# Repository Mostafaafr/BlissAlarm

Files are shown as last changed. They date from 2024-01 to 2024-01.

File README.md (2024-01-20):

Review Assignment Due Date (https://classroom.github.com/a/2yGso8Cl)
# A14-Final Submission
    * Team Number: 13
    * Team Name: BlissAlarm
    * Team Members: Mostafa Afr and Abir Hossain

# Section 1: Video Presentation
Find the video here: https://www.youtube.com/watch?v=Qn7JugjathM&ab_channel=MostafaAfr
Video (https://www.youtube.com/watch?v=Qn7JugjathM&ab_channel=MostafaAfr)

# Section 2: Project Photos & Screenshots

## Final Project Look
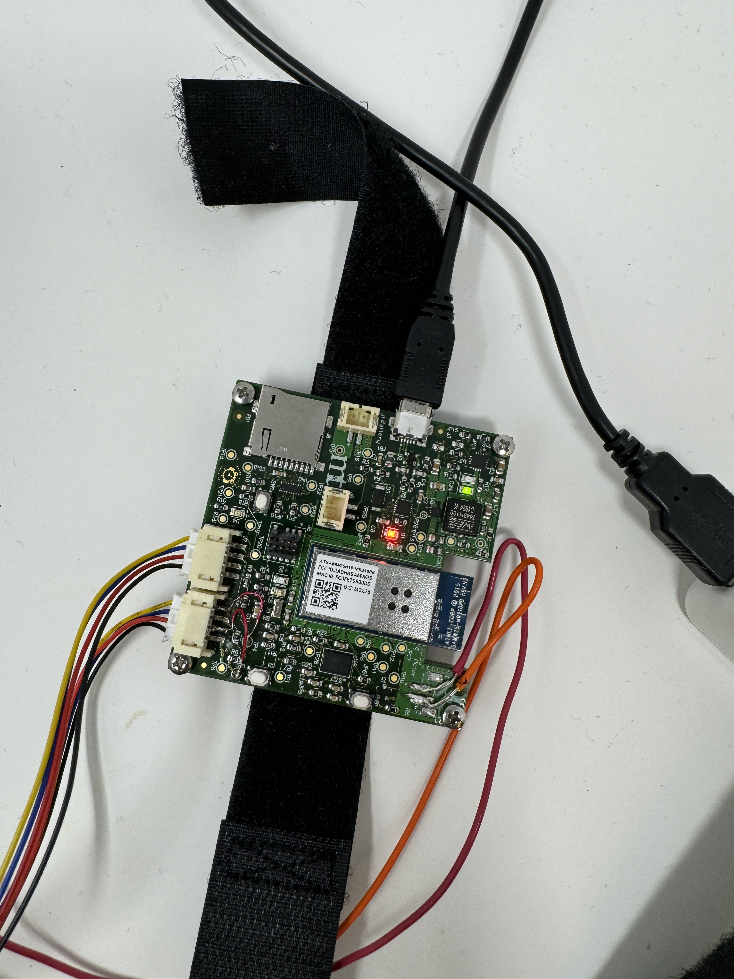
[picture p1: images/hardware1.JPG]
hard1

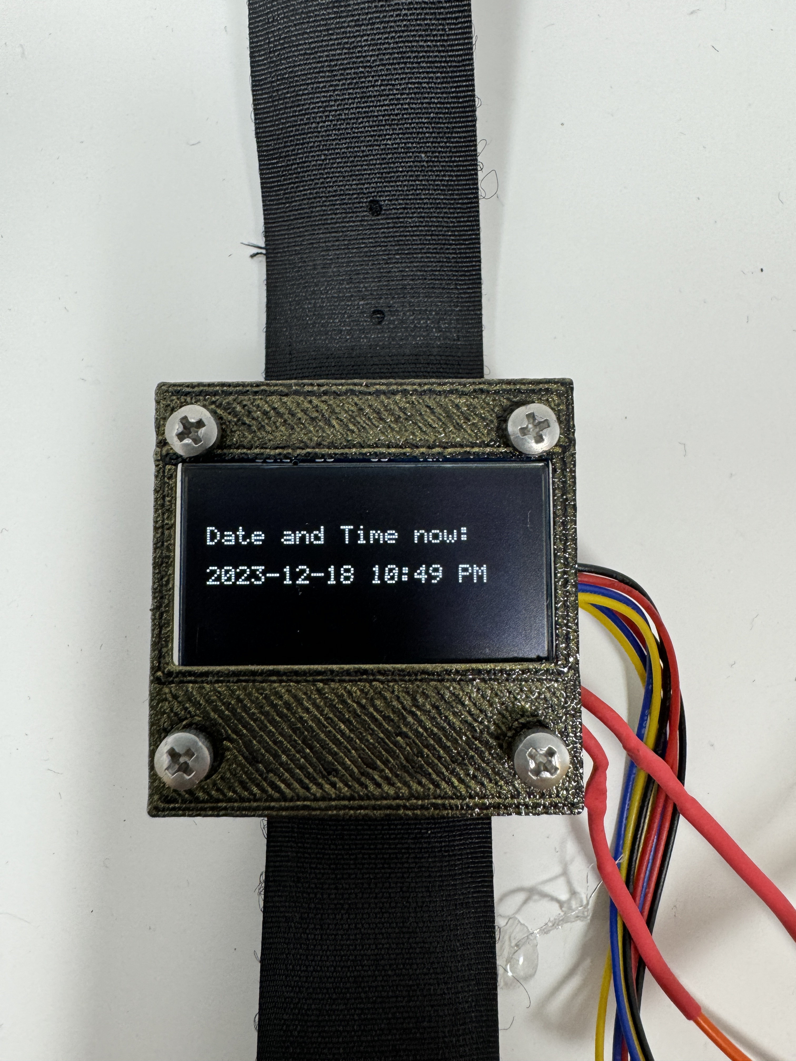
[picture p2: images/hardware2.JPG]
hard2

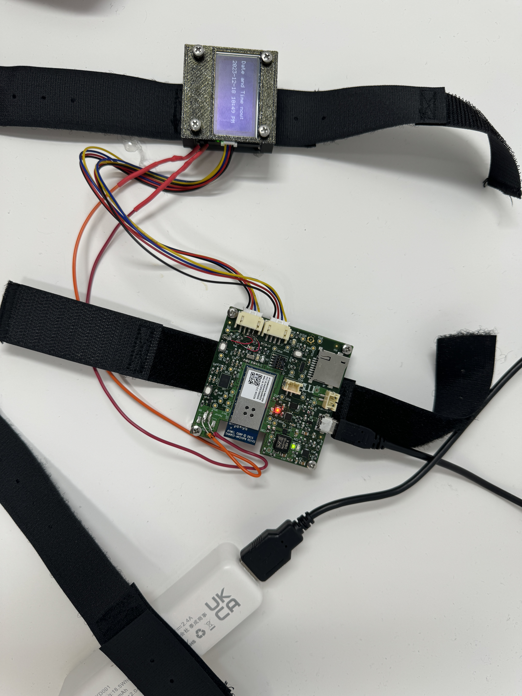
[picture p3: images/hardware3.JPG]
hard3

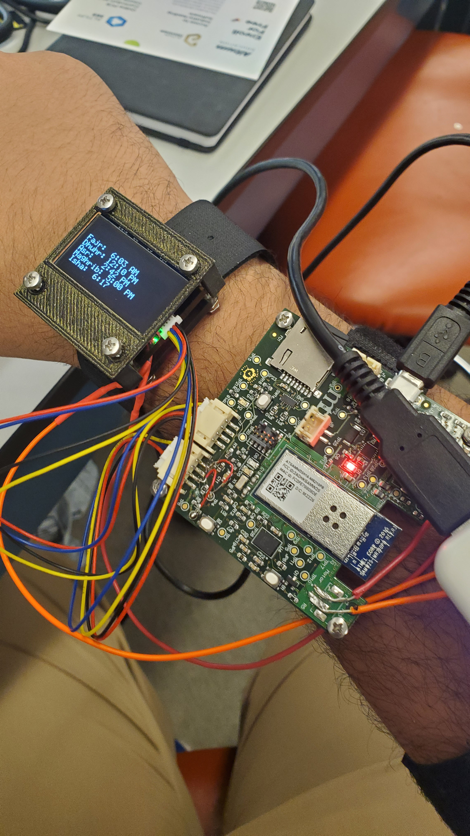
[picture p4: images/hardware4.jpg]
hard4


## PCBA Pictures

### Top 
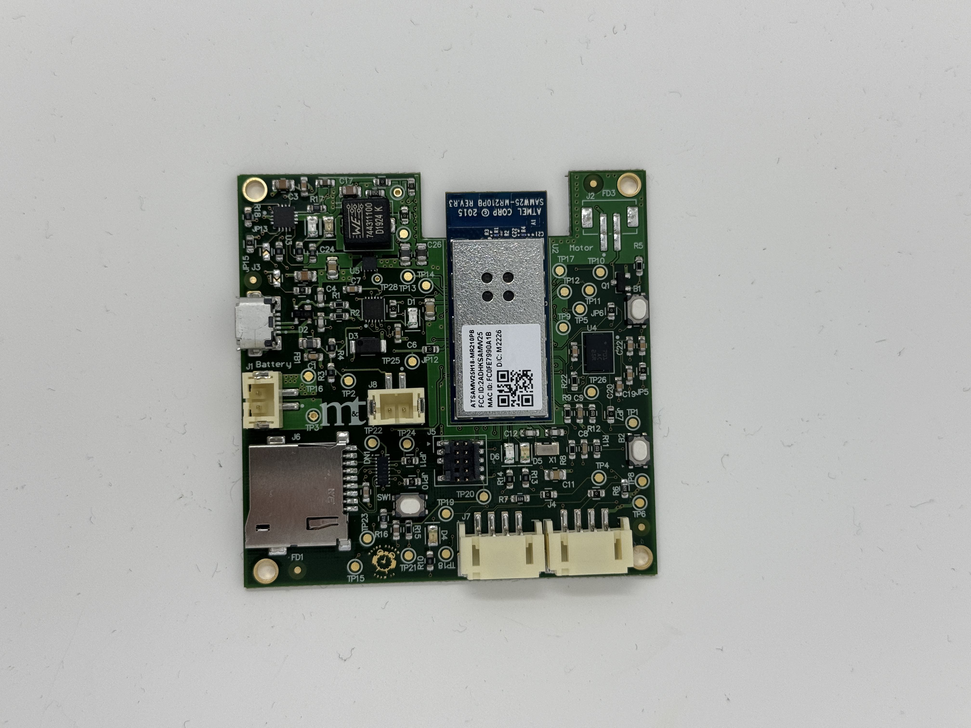
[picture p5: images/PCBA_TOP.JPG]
topPCB

### Bottom 
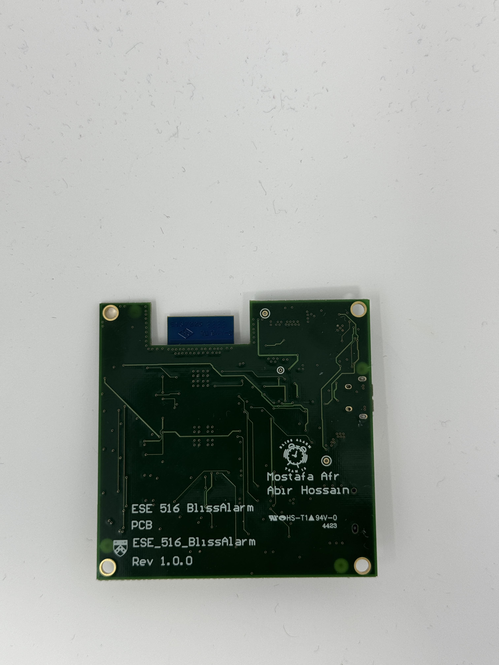
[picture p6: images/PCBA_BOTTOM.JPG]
bottomPCB


## Thermal Images
thermal pic

## Altium Designs

### 2D View
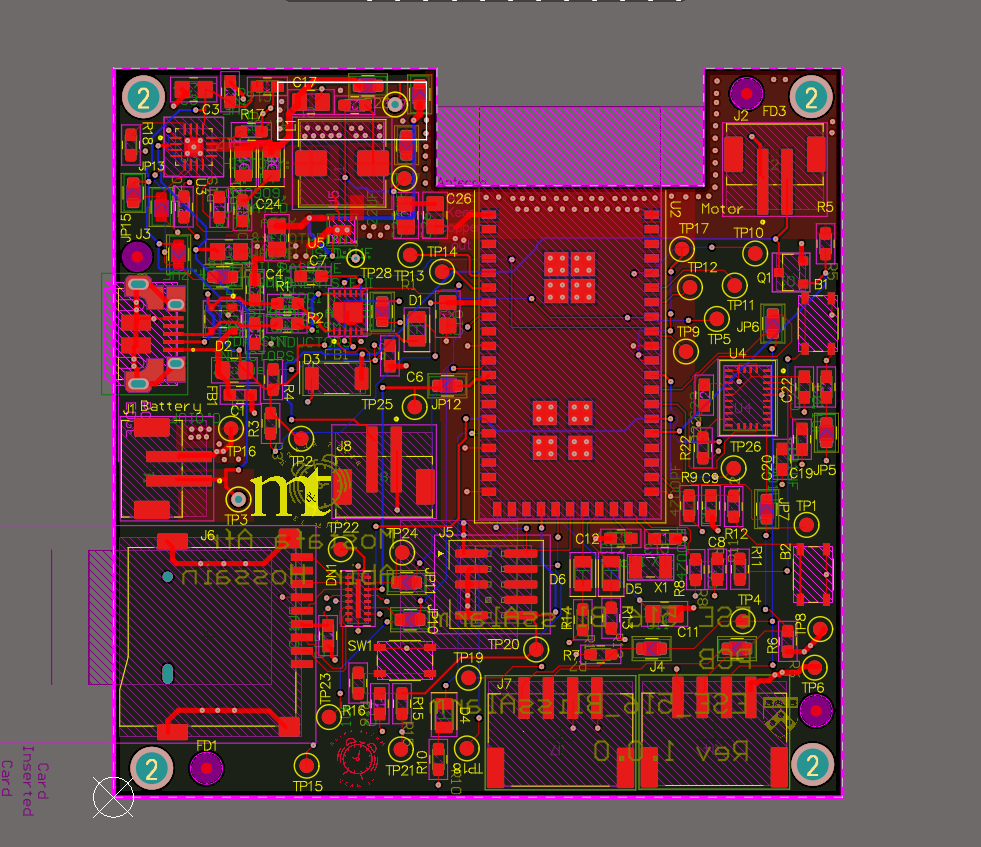
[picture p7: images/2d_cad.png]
2dview

### 3D View
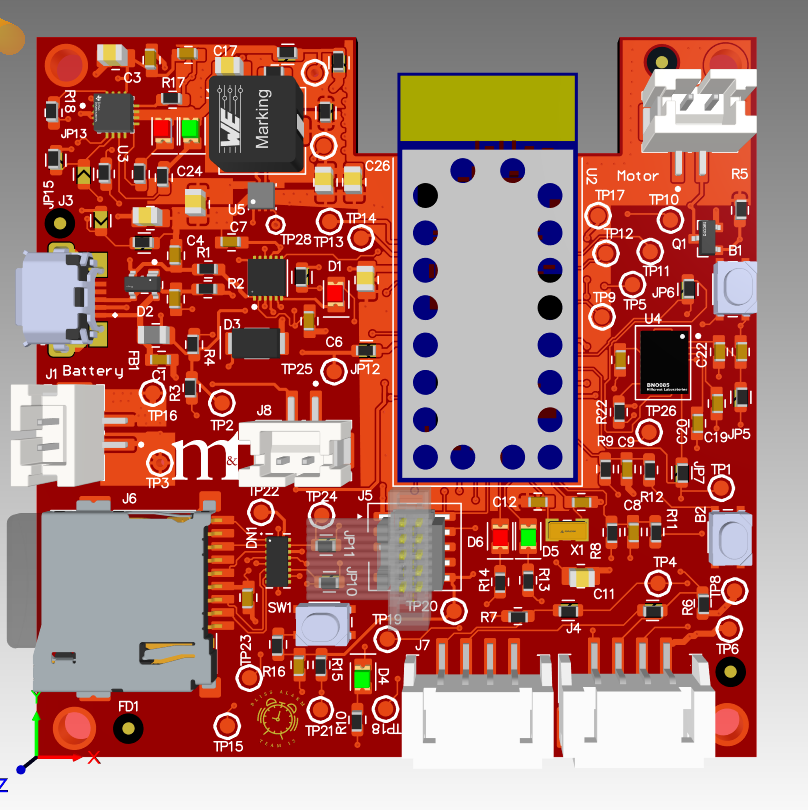
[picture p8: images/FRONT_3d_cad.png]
3dfront
* Top: 
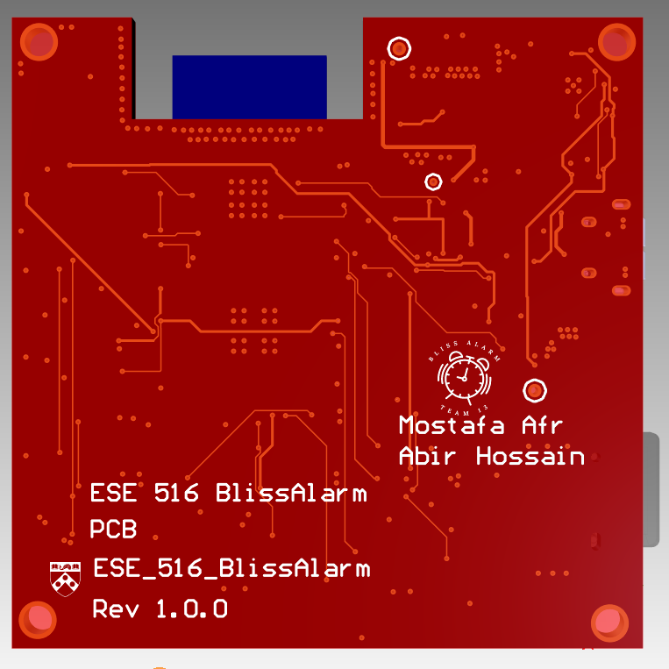
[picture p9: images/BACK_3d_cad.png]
3dback
* Bottom: 

## Node RED Dashboard

### Node RED Frontend
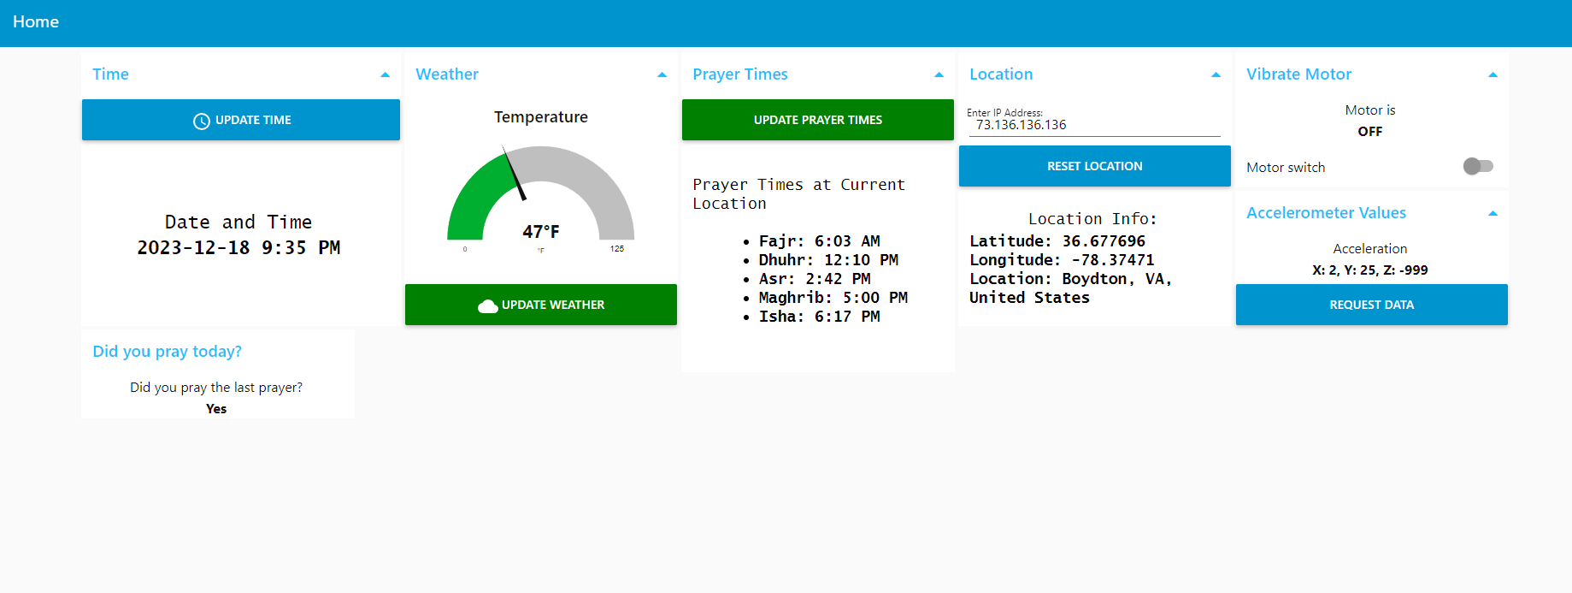
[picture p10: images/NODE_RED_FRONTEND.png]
nodeRed

### Node RED Backend
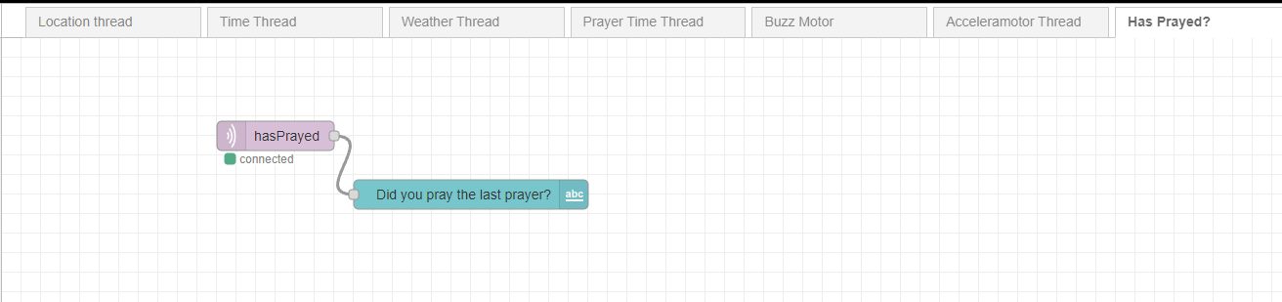
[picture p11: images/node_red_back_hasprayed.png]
prayed
* Checking if prayed: 
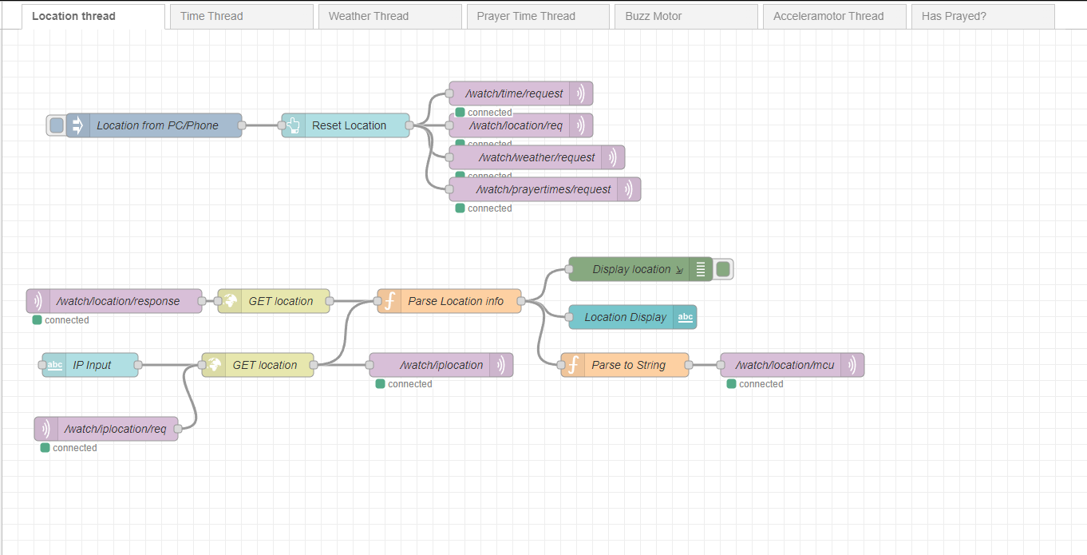
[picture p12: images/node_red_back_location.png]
location
* Location: 
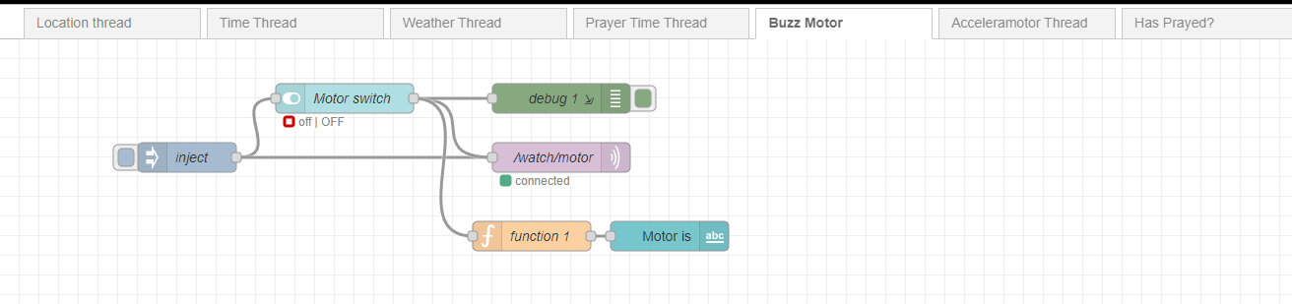
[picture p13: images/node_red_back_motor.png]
motor
* Motor: 
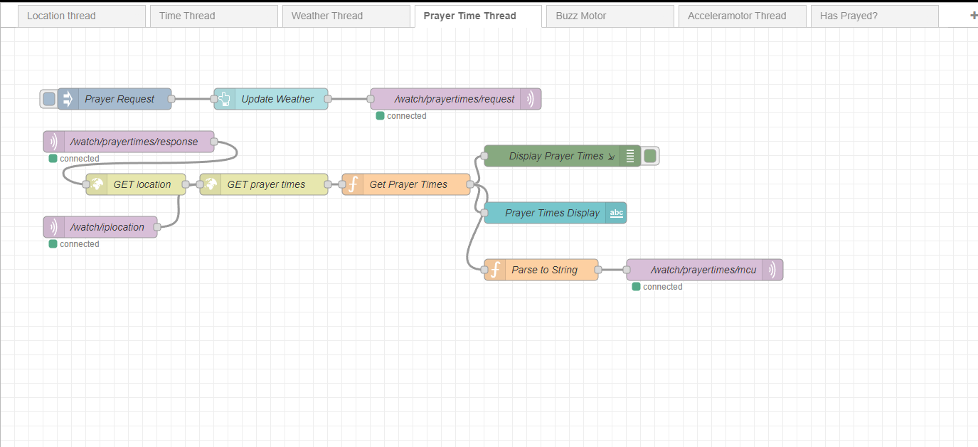
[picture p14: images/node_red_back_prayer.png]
prayer
* Prayer: 
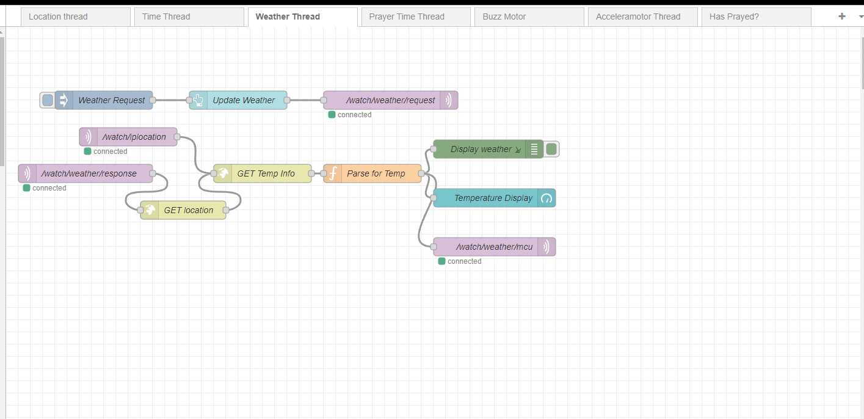
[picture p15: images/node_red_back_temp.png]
temp
* Temperature: 
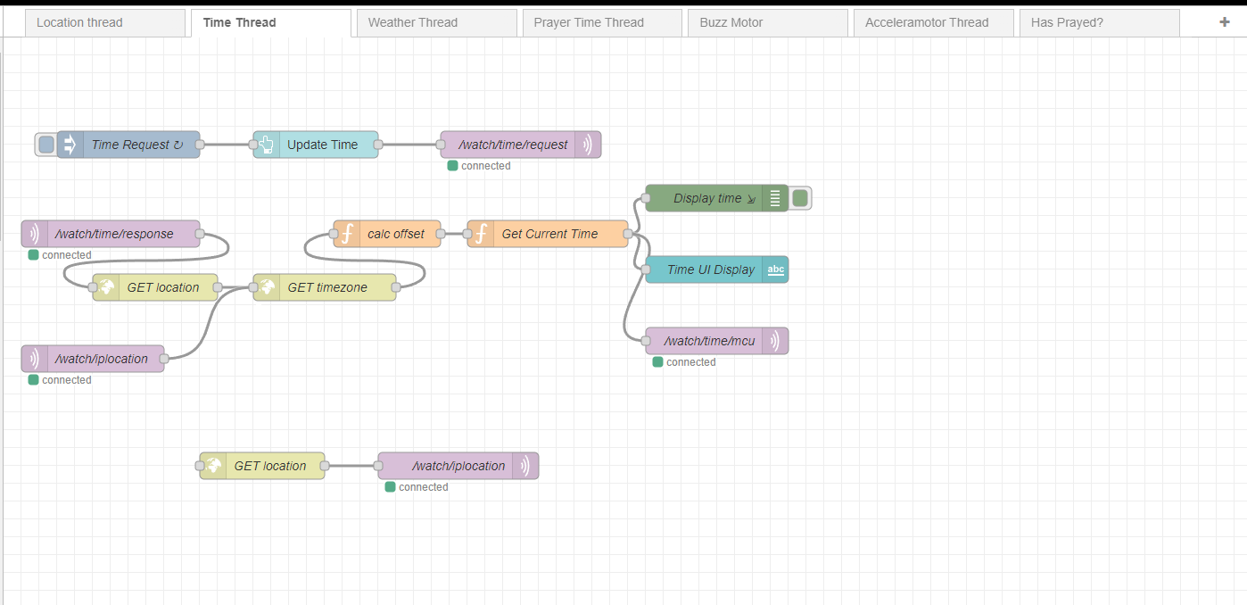
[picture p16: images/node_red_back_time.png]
time
* Time: 

## Block Diagaram
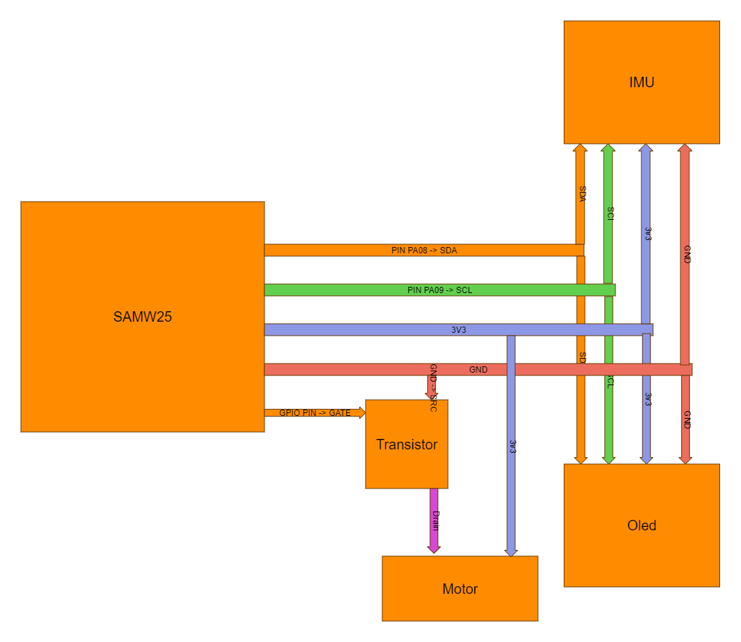
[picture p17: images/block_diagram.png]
blockDiag


# Section 3: Project Summary
## Device Description
Our project solves the issue of Muslims missing prayer times either due to sleep or even during the day. Prayer times change every single day since they are based on the sun’s movement (sunrise, midday, sunset, etc.), and it can be difficult to set an alarm every day for prayer or to always remember to pray on time. Our device connects to the internet and automatically pulls the date, time, and prayer times for that date. It then senses whether you’ve prayed or not using an accelerometer to track if you’ve done the movements for prayer. If you haven’t prayed and the prayer time is coming to an end soon, it will send vibrations with a haptic motor to remind you to pray.

## Inspiration
We were inspired to do this project by Mostafa's 200+ (not joking) alarms on his phone. He can’t wake up to normal alarms well but needs to pray before sunrise every morning, and a strong vibration if you haven’t prayed would be really helpful! This is the case for man Muslims and especially students who have terrible sleep schedules.

## Device Functionality
So the device design is fairly simple. It’s a microcontroller that connects to an OLED via I2C to display things like time, prayer time, etc. It connects to an accelerometer via I2C as well and checks the values at a set interval to try and detect the motions of prayer. It then connects to a haptic motor via a GPIO pin that vibrates if you haven’t prayed. The MCU is WiFi capable, so it connects to MQTT broker on our Azure server which then connects to Node RED to send and receive the data it needs to display. The casing for the watch is 3D printed to fit all the components inside (besides the PCBA which is too large due to the extra testing/debugging components we added). There are also laser cut pieces of acrylic for the bottom of the watch as it made it easier to take apart the watch for debugging. The parts are screwed together or held with adhesive and an ESD strap is used for the watchstrap.

## Project Links
### Node RED Instance
* Backend: http://20.102.106.224:1880/
* Frontend: http://20.102.106.224:1880/ui

### PCBA Link
Altium: https://upenn-eselabs.365.altium.com/designs/55E08EC9-9D23-40D7-89CE-D9C51BA8A47B

## Challenges
We had many, many challenges throughout this project. Our IMU was a major challenge. The IMU we had on our board turned out to have incredibly complex drivers that were difficult to port as it was made for arduino/raspberrypi, and it had its own protocol that wasn’t quite I2C but used I2C in it. We had to switch to a different accelerometer, but thankfully we had an extra JST connector. That extra JST connector unfortunately had the SCL and 3V3 pins swapped, and the trace for the 3V3 pin was really short. That took a couple hours to debug between figuring out the problem, carefully using the knife, and then soldering and resoldering the leads on tight points. We also had many struggles with FreeRtos causing issues. When we pulled pins high they went to .5V instead of 3.3V which is just really weird. We messed with our RTOS scheduling and it fixed it. We had a lot of trouble finding our IMU using I2C even after we switched, which is really odd too. RTOS again caused some issues. We got weird stack overflow errors that sometimes fixed when we unplugged our accelerometer or board. We also had issue with scheduling and getting all of our peripherals to simultaneously work, as sometimes one worked but blocked another. We had problems with MQTT in general as that also had some just weird errors like the Detkin wifi also causing a stack overflow error. We had issues with the screws being too long on our casing and also the casing damaging the OLED we were using (I think that’s what happened at least). Our debug buttons also didn’t work which may have been our own fault in our altium design. A number of things just went wrong and it would take forever to list them all here. We overcame them by asking others in lab for help, reading online, or just trying different things. Each problem came with a set of debugging steps to find a unique solution. Sometimes it was altium, sometimes it was hardware, a lot of times it was RTOS, and sometimes it was unknown Heisenbugs. 

## Prototype Learnings
We learned how to do Altium which we both came in knowing nothing about. That came with a general knowledge of PCBs that we plan to continue into my other products We learned a lot about embedded systems and I2C as well, RTOS, bootloaders, Github, we’ve come out of this class knowing a lot of very necessary skills for prototyping our own projects. We also learned about Node RED and setting up a server, both very useful skills. Node RED in particular is really cool and a nice approach to IoT compared to what we’d done in say ESE 111 with Blynk. We learned about prototyping with different MCUs, particularly a less common one than we did in ESE 350. We even used laser cutting and 3D printing in our final design. We learned a lot of prototyping techniques with regard to coding drivers and picking peripherals and making BOMs (although really boring) that will definitely be useful in our future! If we had to build the device again (which we are actually considering!) we would remove a lot of debugging components since we’ve tested them already. We would fix our mistake of swapping the SCL and 3V3 pins and fix our buttons. We’d definitely use a smaller MCU to make the PCB fit in the watch and choose a bigger screen since those are popular for watches. We’d also change the IMU we are using. Size is really important for our design so we would do a lot of trimming of things to save space.

## Next Steps
We think the steps needed to improve the project are a lot of what we mentioned in question 5. But aside from that, we think we could add a gyroscope. It proved too difficult this time around, but we could do it with more time perhaps. We would also improve the casing to look more professional. We would also work on reliability of the product, as a prototype has its bugs. We would likely add more to the UI on the screen, we think it is fine now, but making it a bit more aesthetic could help it stand out better as a watch. Adding an app could be really helpful too. We also think we should be mainly focusing on size and squeezing the PCB to a much smaller size by shrinking the MCU. 

## Takeaways from ESE 5160 
We learned altium exceptionally well, and learned a lot about I2C. We gained a general understanding of what embedded systems looks like in industry, with power planning, peripheral selection, PCB design, driver coding, etc. We improved in our general knowledge of RTOS based systems, MCUs, etc., and came out just better embedded engineers. We still have a lot to learn, but this was a great introduction to intermediate embedded systems, and we come away with the confidence and ability to build more complex projects!

# Section 4: Codebase
## Attributions for Driver Code

### OLED Driver:
For the OLED Driver, we ported a driver we found on GitHub by elektro155, which can be found at https://github.com/elektro155/OLED-display-SSD1306-library-converted-for-ARM-C-language/tree/master. We attempted to make our own driver, but for this specific OLED it proved to be difficult. The author fo the driver did not post any rules about any specific requirements for attributions. 

### IMU Driver:
For the IMU, we used the IMU that was already used in a previous assignment, so we copied over the driver for that into our final demo. 

### Motor Driver:
We wrote this driver ourselves, and it was on the easier end to do as it was just manipulating the state of a GPIO pin for certain lengths of time.

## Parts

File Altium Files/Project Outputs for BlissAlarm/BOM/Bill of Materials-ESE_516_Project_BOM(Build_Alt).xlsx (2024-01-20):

Line # | Name | Description | Designator | Revision ID | Revision Status | Quantity | Footprint | PCB Package | Fitted | Manufacturer 1 | Manufacturer Part Number 1 | Manufacturer Lifecycle 1 | Supplier 1 | Supplier Part Number 1 | Supplier Unit Price 1 | Supplier Subtotal 1 | CompanyName
 | JST PH to SH Cable |  | A3 |  |  | 1 |  |  |  | Adafruit Industries | 4424 | Unknown | Mouser | 485-4424 | 0.95 | 0.95
 | Vibrating Motor Disc |  | A2 |  |  | 1 |  |  |  | Adafruit Industries | 1201 | Unknown | Mouser | 485-1201 | 1.95 | 1.95
 | 0603 link | 0O link, SMD, 0603, Solder Bridge Option | JP1, JP2, JP3, JP4, JP5, JP6, JP7, JP8, JP9, JP10, JP11, JP12, JP13, JP16 | CMP-00422-5 | Up to date | 14 | 0603_JP_RES |  |  | Stackpole Electronics | RMCF0603ZT0R00 | Volume Production | Mouser | 708-RMCF0603ZT0R00 | 0.008 | 0.112
 | ARM Cortex Debug | 10 Pin Shrouded Header, 0.050", Key Pin 7 | J5 | CMP-002-000013-1 | Up to date | 1 | FTSH-105-01-F-DV-007-K PLUGIN |  |  | Samtec | FTSH-105-01-F-DV-007-K-P-TR | Volume Production | Mouser | 200-FTSH10501FDV7KP | 3.85 | 3.85
 | BNO085 | Accelerometer, Gyroscope, Magnetometer, 9 Axis Sensor I²C, SPI, UART Output | U4 | CMP-00429-1 | Up to date | 1 | FP-BNO085-MFG |  |  | CEVA | BNO085 | Unknown | Digi-Key | 1888-1006-1-ND | 15.97 | 15.97
 | TPS62082DSGR | Buck Step Down Regulator with 2.3 to 6 V Input and 3.3 V Output, -40 to 85 degC, 8-Pin WSON (DSG), Green (RoHS & no Sb/Br) | U5 | CMP-0323-00344-3 | Up to date | 1 | DSG0008A_V |  |  | Texas Instruments | TPS62082DSGR | Volume Production | Mouser | 595-TPS62082DSGR | 1.64 | 1.64
 | CAP 0603 0.01UF 16V 10% X7R | Capacitor Surface Mount 0603 Footprint 0.01UF 16V 10% Tolerance Ceramic X7R | C1 | CMP-011-000185-1 | Up to date | 1 | 0603_CAP | 0603 |  | KEMET | C0603C103K4RACTU | Volume Production | Digi-Key | 399-C0603C103K4RAC7867CT-ND | 0.1 | 0.1
 | CAP 0603 0.1UF 16V 10% X7R | Capacitor Surface Mount 0603 Footprint 0.1UF 16V 10% Tolerance Ceramic X7R | C2, C6, C7, C15, C19, C20, C21, C22, C23 | CMP-011-000221-1 | Up to date | 9 | 0603_CAP | 0603 |  | Yageo | CC0603KRX7R7BB104 | Volume Production | Mouser | 603-CC603KRX7R7BB104 | 0.024 | 0.24
 | CAP 0603 1UF 16V 10% X7R | Capacitor Surface Mount 0603 Footprint 1UF 16V 10% Tolerance Ceramic X7R | C14, C16 | CMP-011-000286-1 | Up to date | 2 | 0603_CAP | 0603 |  | Yageo | CC0603KRX7R7BB105 | Volume Production | Mouser | 603-CC603KRX7R7BB105 | 0.13 | 0.26
 | CAP 0603 18PF 50V 5% C0G | Capacitor Surface Mount 0603 Footprint 18PF 50V 5% Tolerance Ceramic C0G | C12, C13 | CMP-011-000283-1 | Up to date | 2 | 0603_CAP | 0603 |  | Yageo | CC0603JRNPO9BN180 | Volume Production | Digi-Key | 311-1061-1-ND | 0.1 | 0.2
 | CAP 0603 47PF 50V 5% C0G | Capacitor Surface Mount 0603 Footprint 47PF 50V 5% Tolerance Ceramic C0G | C4, C5 | CMP-011-000339-1 | Up to date | 2 | 0603_CAP | 0603 |  | Yageo Phycomp | CC0603JRNPO9BN470 | Volume Production | Digi-Key | 311-1065-1-ND | 0.1 | 0.2
 | CAP 0603 4700PF 50V 5% C0G | Capacitor Surface Mount 0603 Footprint 4700PF 50V 5% Tolerance Ceramic C0G | C8, C9 | CMP-011-000333-1 | Up to date | 2 | 0603_CAP | 0603 |  | Yageo | CC0603JRX7R9BB472 | Volume Production | Digi-Key | 311-3363-1-ND | 0.1 | 0.2
 | CAP 0805 4.7UF 16V 10% X7R | Capacitor Surface Mount 0805 Footprint 4.7UF 16V 10% Tolerance Ceramic X7R | C3, C17, C18 | CMP-011-000523-1 | Up to date | 3 | 0805_CAP | 0805 |  | Yageo | CC0805KKX7R7BB475 | Volume Production | Digi-Key | 311-1883-1-ND | 0.39 | 1.17
 | CAP 0805 10UF 16V 20% X7R | Capacitor Surface Mount 0805 Footprint 10UF 16V 20% Tolerance Ceramic X7R | C10, C11, C24 | CMP-011-000479-1 | Up to date | 3 | 0805_CAP_60H | 0805 |  | Yageo | CC0805KKX5R7BB106 | Volume Production | Mouser | 603-CC805KKX5R7BB106 | 0.34 | 1.02
 | CAP 0805 22UF 10V 20% X5R | Capacitor Surface Mount 0805 Footprint 22UF 10V 20% Tolerance Ceramic X5R | C25, C26 | CMP-011-000507-1 | Up to date | 2 | 0805_CAP_60H | 0805 |  | Yageo | CC0805MKX5R6BB226 | Volume Production | Digi-Key | 311-1900-1-ND | 0.36 | 0.72
 | 10103592-0001LF | Conn Micro USB 2.0 Type B RCP 5 POS 0.65mm Solder RA SMD 5 Terminal 1 Port T/R | J3 | CMP-00092-5 | Up to date | 1 | 10103592-0001LF-Footprint-1 |  |  | Amphenol ICC / FCI | 10103592-0001LF | Unknown | Mouser | 649-10103592-0001LF | 0.34 | 0.34
 | B2B-PH-SM4-TBT(LF)(SN) | Connector Header, PH Series, 2 Position, 2.00mm, 100V, Surface Mount, Solder, Pick and Place, Natural. | J1, J8 | CMP-00418-1 | Up to date | 2 | FP-B2B-PH-SM4-TBT_LF_SN-MFG |  |  | JST | B2B-PH-SM4-TBT | Unknown | Digi-Key | 455-B2B-PH-SM4-TBTCT-ND | 0.81 | 1.62
 | ABS07-32.768KHZ-T | Crystal 32.768kHz ±20ppm (Tol) 12.5pF FUND 70kΩ 2-Pin CSMD T/R | X1 | CMP-0447-00001-4 | Up to date | 1 | FP-ABS07-MFG |  |  | Abracon | ABS07-32.768KHZ-T | Volume Production | Digi-Key | 535-9542-1-ND | 0.66 | 0.66
 | BLM21PG221SN1 | Ferrite Chip 2000 mA 220 Ohms Differential Mode - Single 0805 Footprint | FB1 | CMP-00229-4 | Up to date | 1 | 0805 | 0805 |  | Murata | BLM21PG221SN1D | Volume Production | Digi-Key | 490-1054-1-ND | 0.12 | 0.12
 | 744311100 | General Purpose Inductor, 1uH, 20%, 1 Element, SMD, 2827 | L1 | CMP-002-000018-2 | Up to date | 1 | WE-HCI_7040 |  |  | Wurth Electronics | 744311100 | Volume Production | Mouser | 710-744311100 | 3.8 | 3.8
 | S4B-PH-SM4-TB | Header S4B-PH-SM4-TB, 2.00mm, 4-contacts, side entry, SMT, /1000/reel | J4, J7 | CMP-00426-1 | Up to date | 2 | S4B-PH-SM4-TB-Footprint-1 |  |  | JST | S4B-PH-SM4-TB | Volume Production | Digi-Key | 455-S4B-PH-SM4-TBCT-ND | 0.77 | 1.54 | [NoValue], Penn Electric Racing
 | PTS810SJK250SMTRLFS | Keypad Switch, 1 Switches, SPST, Momentary tactile button, 0.05A, 16VDC, 3.23N, Solder Terminal, Surface Mount-straight | B1, B2, SW1 | CMP-00084-3 | Up to date | 3 | PTS810SJK250SMTRLFS-Footprint-1 |  |  | ITT C&K | PTS810SJK250SMTRLFS | Volume Production | Digi-Key | CKN10503CT-ND | 0.34 | 1.02
 | OLED Screen | Monochrome 1.3" 128x64 OLED graphic display - STEMMA QT / Qwiic | A1 |  |  | 1 |  |  |  | Adafruit Industries | 938 | Unknown | Mouser | 485-938 | 19.95 | 19.95
 | IRLML0040TRPBF | Power Field-Effect Transistor, 3.6A I(D), 40V, 0.056ohm, 1-Element, N-Channel, Silicon, Metal-oxide Semiconductor FET, TO-236AB | Q1 | CMP-00070-3 | Up to date | 1 | FP-SOT23-MFG |  |  | Infineon | IRLML0040TRPBF | Volume Production | Mouser | 942-IRLML0040TRPBF | 0.4 | 0.4
 | BQ24075RGTR | Power Supply Support Circuit, Adjustable, 1 Channel, 6.6, PQCC16 | U3 | CMP-00080-5 | Up to date | 1 | FP-RGT0016C-IPC_A |  |  | Texas Instruments | BQ24075RGTR | Volume Production | Mouser | 595-BQ24075RGTR | 2.29 | 2.29
 | STPS360AFY | Rectifier Diode, Schottky, 1 Phase, 1 Element, 60V V(RRM), Silicon | D3 | CMP-00069-1 | Up to date | 1 | ST-SOD128FL |  |  | STMicroelectronics | STPS360AFY | Volume Production | Mouser | 511-STPS360AFY | 0.44 | 0.44
 | RES 0603 1K 1% | Resistor Surface Mount, 1K Ohms, 0603 Footprint, 1% Tolerance 0.1W | R3, R4, R10, R13, R14, R19, R20, R21 | CMP-005-002503-3 | Up to date | 8 | 0603_RES | 0603 |  | Stackpole Electronics | RMCF0603FT1K00 | Volume Production | Digi-Key | RMCF0603FT1K00CT-ND | 0.014 | 0.14
 | RES 0603 1.13K 1% | Resistor Surface Mount, 1.13K Ohms, 0603 Footprint, 1% Tolerance 0.1W | R17, R18 | CMP-005-001984-2 | Up to date | 2 | 0603_RES | 0603 |  | Stackpole Electronics | RMCF0603FT1K13 | Volume Production | Digi-Key | RMCF0603FT1K13CT-ND | 0.014 | 0.14
 | RES 0603 2.1K 1% | Resistor Surface Mount, 2.1K Ohms, 0603 Footprint, 1% Tolerance 0.1W | R6, R7 | CMP-005-002520-2 | Up to date | 2 | 0603_RES | 0603 |  | Stackpole Electronics | RMCF0603FT2K10 | Volume Production | Digi-Key | RMCF0603FT2K10CT-ND | 0.014 | 0.14
 | RES 0603 10K 1% | Resistor Surface Mount, 10K Ohms, 0603 Footprint, 1% Tolerance 0.1W | R5, R15, R22 | CMP-005-002156-3 | Up to date | 3 | 0603_RES | 0603 |  | Stackpole Electronics | RMCF0603FT10K0 | Volume Production | Mouser | 708-RMCF0603FT10K0 | 0.009 | 0.09
 | RES 0603 27 1% | Resistor Surface Mount, 27 Ohms, 0603 Footprint, 1% Tolerance 0.1W | R1, R2 | CMP-005-002764-2 | Up to date | 2 | 0603_RES | 0603 |  | Stackpole Electronics | RMCF0603FT27R0 | Volume Production | Digi-Key | RMCF0603FT27R0CT-ND | 0.014 | 0.14
 | RES 0603 39 1% | Resistor Surface Mount, 39 Ohms, 0603 Footprint, 1% Tolerance 0.1W | R11, R12 | CMP-005-003070-2 | Up to date | 2 | 0603_RES | 0603 |  | Stackpole Electronics | RMCF0603FT39R0 | Volume Production | Digi-Key | RMCF0603FT39R0CT-ND | 0.014 | 0.14
 | RES 0603 100 1% | Resistor Surface Mount, 100 Ohms, 0603 Footprint, 1% Tolerance 0.1W | R16 | CMP-005-002125-2 | Up to date | 1 | 0603_RES | 0603 |  | Stackpole Electronics | RMCF0603FT100R | Volume Production | Digi-Key | RMCF0603FT100RCT-ND | 0.1 | 0.1
 | RES 0603 100K 1% | Resistor Surface Mount, 100K Ohms, 0603 Footprint, 1% Tolerance 0.1W | R8, R9 | CMP-005-002132-2 | Up to date | 2 | 0603_RES | 0603 |  | Stackpole Electronics | RMCF0603FT100K | Volume Production | Digi-Key | RMCF0603FT100KCT-ND | 0.014 | 0.14
 | RES 0603 178K 1% | Resistor Surface Mount, 178K Ohms, 0603 Footprint, 1% Tolerance 0.1W | R23 | CMP-005-002436-2 | Up to date | 1 | 0603_RES | 0603 |  | Stackpole Electronics | RMCF0603FT178K | Volume Production | Digi-Key | RMCF0603FT178KCT-ND | 0.1 | 0.1
 | LSM0805452V | Single Color LED, Green, 0805 | D4, D5, D8 | CMP-00038-3 | Up to date | 3 | LED_0805 |  |  | Visual Communications | LSM0805452V | Volume Production | Digi-Key | 28-LSM0805452VCT-ND | 0.4 | 1.2
 | LSM0805412V | Single Color LED, RED, 0805 | D1, D6, D7 | CMP-00026-00001-1 | Up to date | 3 | LED_0805_RED |  |  | Visual Communications | LSM0805412V | Volume Production | Digi-Key | 28-LSM0805412VCT-ND | 0.46 | 1.38
 | ECLAMP2410PQTCT | Trans Voltage Suppressor Diode, 5V V(RWM), Bidirectional, 7 Element, Silicon with EMI Filter | DN1 | CMP-00096-2 | Up to date | 1 | ECLAMP2410PQTCT-Footprint-1 |  |  | Semtech | ECLAMP2410PQTCT | Volume Production | Mouser | 947-ECLAMP2410PQTCT | 1.44 | 1.44
 | PRTR5V0U2X,215 | Trans Voltage Suppressor Diode, 5.5V V(RWM), Unidirectional, 1 Element, Silicon | D2 | CMP-00371-1 | Up to date | 1 | FP-SOT143B-NXP |  |  | Nexperia | PRTR5V0U2X,215 | Volume Production | Mouser | 771-PRTR5V0U2X-T/R | 0.44 | 0.44
 | FT234XD-R | USB Bridge, USB to UART USB 2.0 UART Interface 12-DFN (3x3) | U1 | CMP-00104-3 | Up to date | 1 | FP-DFN-12-MFG |  |  | FTDI | FT234XD-R | Volume Production | Digi-Key | 768-1178-1-ND | 2.26 | 2.26
 | ATSAMW25H18-MR210 | WiFi 802.11b/g/n Transceiver Module 2.412GHz ~ 2.484GHz Integrated, Trace Surface Mount, Integrated SAMD21 Cortex M0+ | U2 | CMP-00071-2 | Out of date | 1 | ATSAMW25H18-MR210-Footprint-1 |  |  | Microchip | ATSAMW25H18-MR210PB1954 | Volume Production | Digi-Key | ATSAMW25H18-MR210PB1954-ND | 15.3 | 15.3
 | 693071020811 | WR-CRD Micro SD Card Connector Push & Push | J6 | CMP-00419-3 | Up to date | 1 | 693071020811 |  |  | Wurth Electronics | 693071020811 | Volume Production | Mouser | 710-693071020811 | 3.96 | 3.96

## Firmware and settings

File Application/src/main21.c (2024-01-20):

/**************************************************************************/ /**
* @file      main.c
* @brief     Main application entry point
* @author    Eduardo Garcia
* @date      2020-02-15
* @copyright Copyright Bresslergroup\n
*            This file is proprietary to Bresslergroup.
*            All rights reserved. Reproduction or distribution, in whole
*            or in part, is forbidden except by express written permission
*            of Bresslergroup.
******************************************************************************/


/******************************************************************************
* Includes
******************************************************************************/
#include <errno.h>
#include "asf.h"
#include "main.h"
#include "stdio_serial.h"
#include "SerialConsole.h"
#include "FreeRTOS.h"
#include "driver/include/m2m_wifi.h"
#include "CliThread/CliThread.h"
#include "SeesawDriver/Seesaw.h"
#include "IMU/lsm6dso_reg.h"
#include "UiHandlerThread\UiHandlerThread.h"
#include "OLed/oled.h"
#include "MotorDriver/motor_driver.h"
#include "IMU/lsm6dso_reg.h"
#include "WifiHandlerThread/WifiHandler.h"
/******************************************************************************
* Defines and Types
******************************************************************************/
#define APP_TASK_ID 0 /**< @brief ID for the application task */
#define CLI_TASK_ID 1 /**< @brief ID for the command line interface task */
#define OLED_TASK_SIZE 128 // OLED task stack size
#define OLED_PRIORITY (tskIDLE_PRIORITY + 1) // OLED task priority
#define MOTOR_TASK_STACK_SIZE (128)
#define MOTOR_TASK_PRIORITY (tskIDLE_PRIORITY + 1)
//#define BOOT_TEST 1 //Uncomment me to compile boot test.

/******************************************************************************
* Local Function Declaration
******************************************************************************/
void vApplicationIdleHook(void);
static void StartTasks(void);
void vApplicationDaemonTaskStartupHook(void);
void vOledTask(void *pvParameters); // OLED task function
void vMotorTask(void *pvParameters); // Motor task function
/******************************************************************************
* Variables
******************************************************************************/
static TaskHandle_t cliTaskHandle = NULL; //!< CLI task handle
static TaskHandle_t daemonTaskHandle = NULL; //!< Daemon task handle
static TaskHandle_t uiTaskHandle = NULL; //!< UI task handle
static TaskHandle_t oledTaskHandle = NULL; // OLED task handle
static TaskHandle_t motorTaskHandle = NULL; // Motor task handle
static TaskHandle_t wifiTaskHandle = NULL; // WiFi task handle


char bufferPrint[64]; //Buffer for daemon task

/**
 * \brief Main application function.
 *
 * Application entry point.
 *
 * \return program return value.
 */
int main(void)
{
/* Initialize the board. */
system_init();

/* Initialize the UART console. */
InitializeSerialConsole();

//Initialize trace capabilities
vTraceEnable(TRC_START);
    // Start FreeRTOS scheduler
    vTaskStartScheduler();

return 0; //Will not get here
}

/**************************************************************************/ /**
* function          vApplicationDaemonTaskStartupHook
* @brief            Initialization code for all subsystems that require FreeRToS
* @details This function is called from the FreeRToS timer task. Any code
* here will be called before other tasks are initilized.
* @param[in]        None
* @return           None
*****************************************************************************/
volatile uint8_t data[256];
void vApplicationDaemonTaskStartupHook(void)
{

SerialConsoleWriteString("\r\n\r\n-----ESE516 Main Program-----\r\n");

//Initialize HW that needs FreeRTOS Initialization
SerialConsoleWriteString("\r\n\r\nInitialize HW...\r\n");
if (I2cInitializeDriver() != STATUS_OK)
{
SerialConsoleWriteString("Error initializing I2C Driver!\r\n");
}
else
{
SerialConsoleWriteString("Initialized I2C Driver!\r\n");
}

if(0 != InitializeSeesaw())
{
SerialConsoleWriteString("Error initializing Seesaw!\r\n");
}
else
{
SerialConsoleWriteString("Initialized Seesaw!\r\n");
}
motor_driver_init(MOTOR_DRIVER_PIN); // Initialize the motor driver

uint8_t whoamI = 0;
(lsm6dso_device_id_get(GetImuStruct(), &whoamI));
char iAM[50];
snprintf(iAM, sizeof(iAM), "I am %x \r\n", whoamI);
SerialConsoleWriteString(iAM);
if (whoamI != LSM6DSO_ID){
SerialConsoleWriteString("Cannot find IMU!\r\n");
}
else
{
SerialConsoleWriteString("IMU found!\r\n");
if(InitImu() == 0)
{
SerialConsoleWriteString("IMU initialized!\r\n");
}
else
{
SerialConsoleWriteString("Could not initialize IMU\r\n");
}
}



StartTasks();

vTaskSuspend(daemonTaskHandle);
}

/**************************************************************************//**
* function          StartTasks
* @brief            Initialize application tasks
* @details
* @param[in]        None
* @return           None
*****************************************************************************/
static void StartTasks(void)
{
    snprintf(bufferPrint, 64, "Heap before starting tasks: %d\r\n", xPortGetFreeHeapSize());
    SerialConsoleWriteString(bufferPrint);

    // Initialize Tasks here

    if (xTaskCreate(vCommandConsoleTask, "CLI_TASK", CLI_TASK_SIZE, NULL, CLI_PRIORITY, &cliTaskHandle) != pdPASS) {
        SerialConsoleWriteString("ERR: CLI task could not be initialized!\r\n");
    }

    snprintf(bufferPrint, 64, "Heap after starting CLI: %d\r\n", xPortGetFreeHeapSize());
    SerialConsoleWriteString(bufferPrint);

    if(xTaskCreate(vUiHandlerTask, "UI Task", UI_TASK_SIZE, NULL, UI_TASK_PRIORITY, &uiTaskHandle) != pdPASS) {
        SerialConsoleWriteString("ERR: UI task could not be initialized!\r\n");
    }

    snprintf(bufferPrint, 64, "Heap after starting UI Task: %d\r\n", xPortGetFreeHeapSize());
    SerialConsoleWriteString(bufferPrint);

    // Create OLED task
    if (xTaskCreate(vOledTask, "OLED Task", OLED_TASK_SIZE, NULL, OLED_PRIORITY, &oledTaskHandle) != pdPASS) {
        SerialConsoleWriteString("ERR: OLED task could not be initialized!\r\n");
    }
	if (xTaskCreate(vMotorTask, "Motor Task", MOTOR_TASK_STACK_SIZE, NULL, MOTOR_TASK_PRIORITY, &motorTaskHandle) != pdPASS) {
		SerialConsoleWriteString("Error: Motor task could not be created!\r\n");
	}
	if (xTaskCreate(vWifiTask, "Wifi Task", WIFI_TASK_SIZE, NULL, WIFI_PRIORITY, &wifiTaskHandle) != pdPASS) {
		SerialConsoleWriteString("Error: WiFi task could not be created!\r\n");
	}
}







static void configure_console(void)
{

stdio_base = (void *)GetUsartModule();
ptr_put = (int (*)(void volatile*,char))&usart_serial_putchar;
ptr_get = (void (*)(void volatile*,char*))&usart_serial_getchar;


# if defined(__GNUC__)
// Specify that stdout and stdin should not be buffered.
setbuf(stdout, NULL);
setbuf(stdin, NULL);
// Note: Already the case in IAR's Normal DLIB default configuration
// and AVR GCC library:
// - printf() emits one character at a time.
// - getchar() requests only 1 byte to exit.
#  endif
//stdio_serial_init(GetUsartModule(), EDBG_CDC_MODULE, &usart_conf);
//usart_enable(&cdc_uart_module);
}


void vApplicationMallocFailedHook(void)
{
SerialConsoleWriteString("Error on memory allocation on FREERTOS!\r\n");
while(1);
}

void vApplicationStackOverflowHook(void)
{
SerialConsoleWriteString("Error on stack overflow on FREERTOS!\r\n");
while(1);
}


/**************************************************************************//**
* function          vOledTask
* @brief            Task for controlling the OLED display
* @details
* @param[in]        pvParameters Parameter passed into the task
* @return           None
*****************************************************************************/
void vOledTask(void *pvParameters)
{

  i2c_clear(); // Clear the OLED display
  i2c_setCursor(0, 0); // Set the cursor to the top-left position
  i2c_print("Hello BlissAlarm!"); // Print the message
  /*vTaskDelay(pdMS_TO_TICKS(5000));*/
//   i2c_clear(); 

    for(;;) {
        // OLED task loop
        vTaskDelay(pdMS_TO_TICKS(5000)); // Delay for a period
    }
}
void vMotorTask(void *pvParameters)
{
	for (int i = 0; i < 10000; i++) {
		// Example: Vibrate the motor continuously
		/*motor_vibrate_continuous();*/

		// Delay to prevent task from running continuously
// 		vTaskDelay(pdMS_TO_TICKS(1000)); // Adjust the delay as needed
// 
// 		// Example: Stop the motor
// 		motor_stop();

		// Another delay
		vTaskDelay(pdMS_TO_TICKS(1000));
	}
}

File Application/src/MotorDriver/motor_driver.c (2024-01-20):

/**
 * @file motor_driver.c
 * @author Abir Hossain (abirh@seas.upenn.edu)
 * @author Mostafa Afr (abirh@seas.upenn.edu)
 * @brief Driver to handle operating motor vibrations. 
 * @version 0.1
 * @date 2023-12-04
 * 
 * @copyright Copyright (c) 2023
 * 
 */

#include "motor_driver.h"
#include <asf.h> // Assuming Atmel Software Framework is used

static int motor_gpio_pin;

/**
 * @brief Initializes the motor driver, and
 * sets the GPIO pin the motor is connected to.
 * 
 * @param gpio_pin Pin the motor is connected to
 * on the board
 */
void motor_driver_init(int gpio_pin) {
    motor_gpio_pin = gpio_pin;
    // Configure the GPIO pin as output
    struct port_config pin_conf;
    port_get_config_defaults(&pin_conf);
    pin_conf.direction  = PORT_PIN_DIR_OUTPUT;
    port_pin_set_config(motor_gpio_pin, &pin_conf);
}

/**
 * @brief Sets the motor to vibrate 
 * continuously. 
 * 
 */
void motor_vibrate_continuous(void) {
    port_pin_set_output_level(motor_gpio_pin, true);
}

/**
 * @brief Sets the motor to vibrate in
 * bursts at a time.
 * 
 * @param burst_duration_ms Time to vibrate for (in ms)
 * @param pause_duration_ms Pause time in between vibrations (in ms)
 * @param repeat_count Number of times to repeat bursts
 */
void motor_vibrate_bursts(int burst_duration_ms, int pause_duration_ms, int repeat_count) {
    for (int i = 0; i < repeat_count; i++) {
        port_pin_set_output_level(motor_gpio_pin, true);
        delay_ms(burst_duration_ms);
        port_pin_set_output_level(motor_gpio_pin, false);
        delay_ms(pause_duration_ms);
    }
}

/**
 * @brief Vibrates motor for a designated
 * amount of time.
 * 
 * @param duration_ms Time to vibrate motor for.
 */
void motor_vibrate_timed(int duration_ms) {
    motor_vibrate_continuous();
    delay_ms(duration_ms);
    motor_stop();
}

/**
 * @brief Vibrates the motor in different
 * pattersns.
 * 
 * @param pattern Pattern for motor to vibrate
 * in.
 * @param length Length of pattern.
 */
void motor_vibrate_pattern(int pattern[], int length) {
    for (int i = 0; i < length; ++i) {
        if (pattern[i] > 0) {
            port_pin_set_output_level(motor_gpio_pin, true);
            delay_ms(pattern[i]);
        } else {
            port_pin_set_output_level(motor_gpio_pin, false);
            delay_ms(-pattern[i]);
        }
    }
}

/**
 * @brief Sets the pin output level to LOW,
 * so the motor stops vibrating.
 * 
 */
void motor_stop(void) {
    port_pin_set_output_level(motor_gpio_pin, false);
}

/**
 * @brief Various notifiations for the user, which
 * send the motor different patters of vibrations
 * based on the notification type. 
 * 
 * @param notif 
 */
void notify_user(int notif) {
    switch (notif) {
        case 1:
            {int pattern1[] = {100, -100, 100, -100, 100};
            motor_vibrate_pattern(pattern1, 5);
            break;}

        case 2: 
            {int pattern2[] = {1300, -1000, 1300, -1000, 1300, -1000};
            motor_vibrate_pattern(pattern2, 6);
            break;}

        case 3:
            {int pattern3[] = {100, -100, 100, -500, 100, -100, 100};
            motor_vibrate_pattern(pattern3, 7);
            break;}

        case 4: 
            {int pattern4[] = {500, -200, 500, -200, 500};
            motor_vibrate_pattern(pattern4, 5);
            break;}

        case 5: 
            {int pattern5[] = {300, -100};
            motor_vibrate_pattern(pattern5, 2);
            break;}

        case 6: 
            {int pattern6[] = {300, -100, 200, -100, 100, -100};
            motor_vibrate_pattern(pattern6, 6);
            break;}

        case 7:
            {int pattern7[] = {300, -100, 300, -100, 300, -500, 300, -100, 300, -100, 300};
            motor_vibrate_pattern(pattern7, 11);
            break;}

        case 8: 
            {int pattern8[] = {100, -50, 100, -50, 100, -50, 100, -50, 100, -50, 100, -50};
            motor_vibrate_pattern(pattern8, 12);
            break;}

        case 9:
            {int pattern9[] = {200, -100, 200, -100, 200, -300, 200, -100, 200};
            motor_vibrate_pattern(pattern9, 9);
            break;}

        case 10: 
            {int pattern10[] = {300, -300, 100};
            motor_vibrate_pattern(pattern10, 3);
            break;}

        default:
            break;
    }
}
